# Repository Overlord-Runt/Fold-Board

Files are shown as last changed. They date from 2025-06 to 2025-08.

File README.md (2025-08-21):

# Fold Board
Made By Overlord Runt // Taran The Idiot
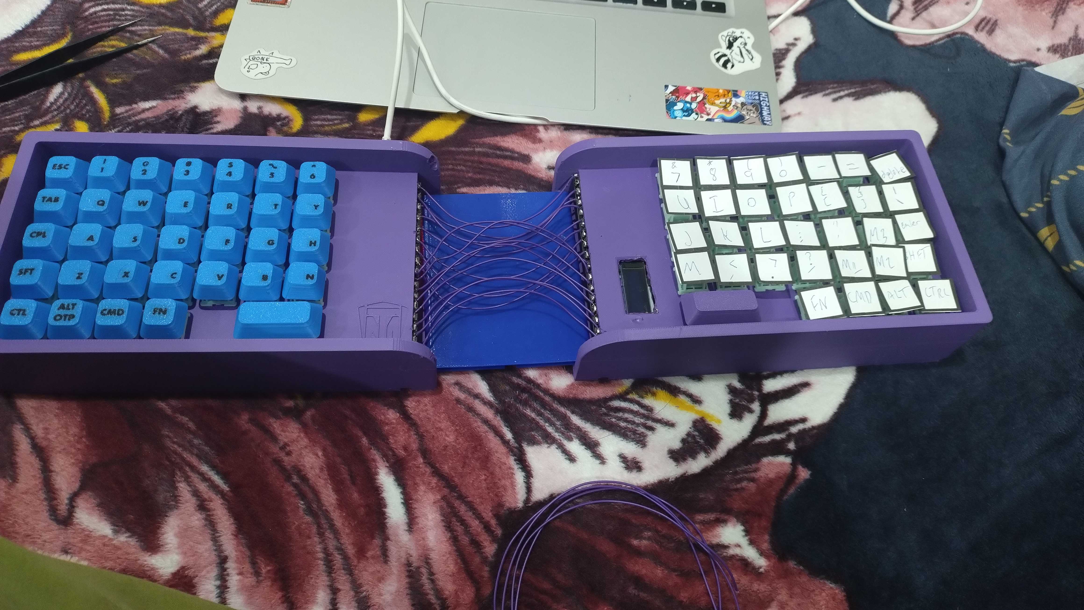
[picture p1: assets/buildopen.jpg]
start


## The Fold Board
Its the second keyboard in my line of Taranium boards. It is a keyboard that folds! It has 66 Keys and an OLED for funny stuff.

If you like this project, please give it a star!

YouTube vid: https://youtube.com/shorts/LQNGhtRMvZQ?si=ZyAIBXtM6X78Itwt

## CAD

Here is a full [CAD Build](https://cad.onshape.com/documents/464e86edd9a4b3695068071c/w/4e80d06eb9a86776c724470c/e/258c53a4e91dc0ec03e526f0) of the keyboard.\
It uses a rubber band to hold the 2 halves together and I am probably gonna have to work on the joint a bit when i get the parts.

The case is 44cm tall when layed flat out which is pretty good for a folding board. I made sure to keep the joint loose but strong enough to stay on so it doesnt wear down as muhttps://youtube.com/shorts/LQNGhtRMvZQ?si=ZyAIBXtM6X78Itwtch and stays nice. I suggest printing it from petg so you can get more slip.

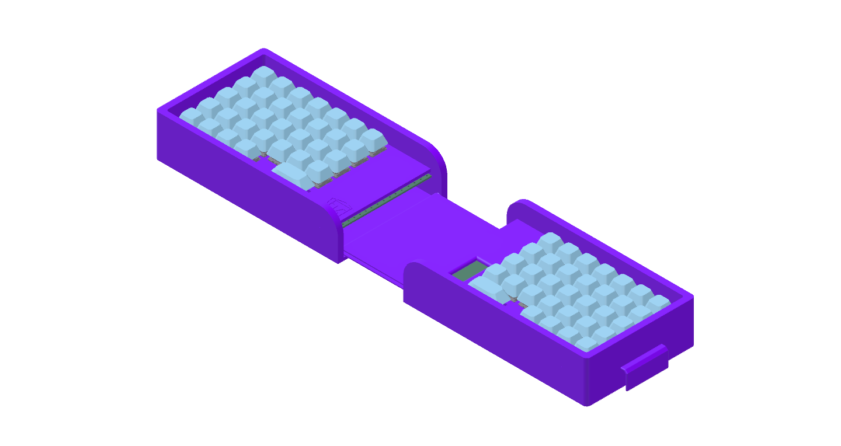
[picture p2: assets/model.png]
mod


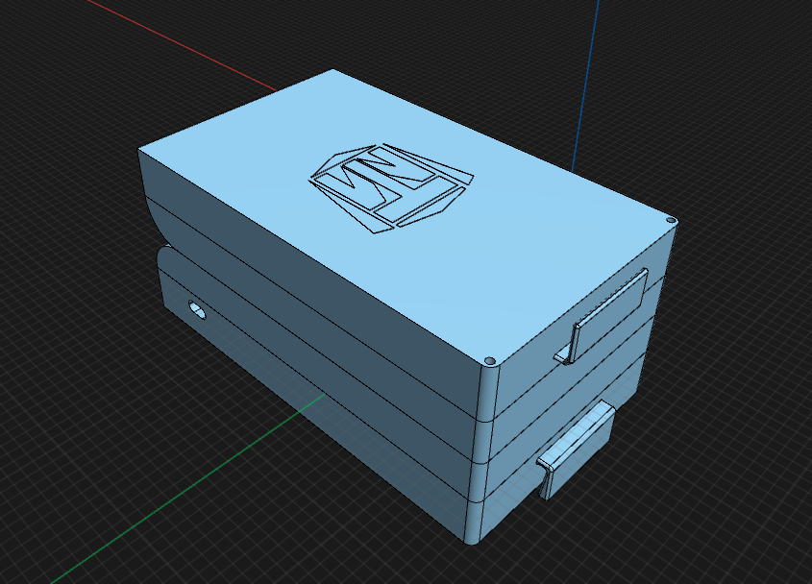
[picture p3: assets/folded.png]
fold


Here are some shots of what it looks like open and folded.

I spent majority of my time here going through different renditions of the bridge and trying different ways to make the fold work while keeping it as a keyboard that it viable to use.

## PCB

The pcb was done pretty quickly and I only did about 1 revision while making it.\
The pcb folder contains the original design files while right and left side have the files with the respective side isolated for fabrication purposes. gerbers can also be found in those folders.

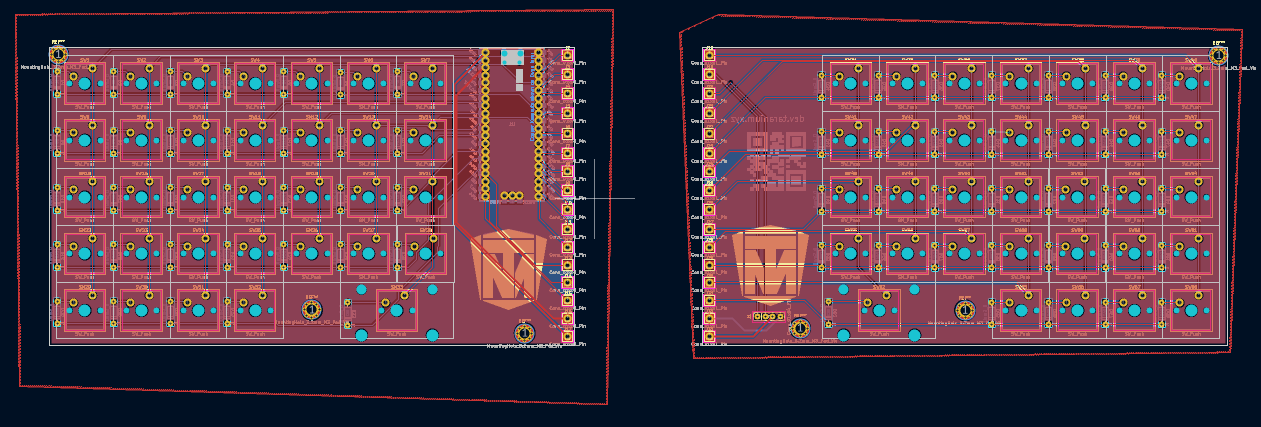
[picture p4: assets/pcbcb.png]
b


I used 16 jumper wires to bridge the connections of one half to the other instead of going for the traditional approach with trrs. I think will add a nice look to it, especially across the bridge.

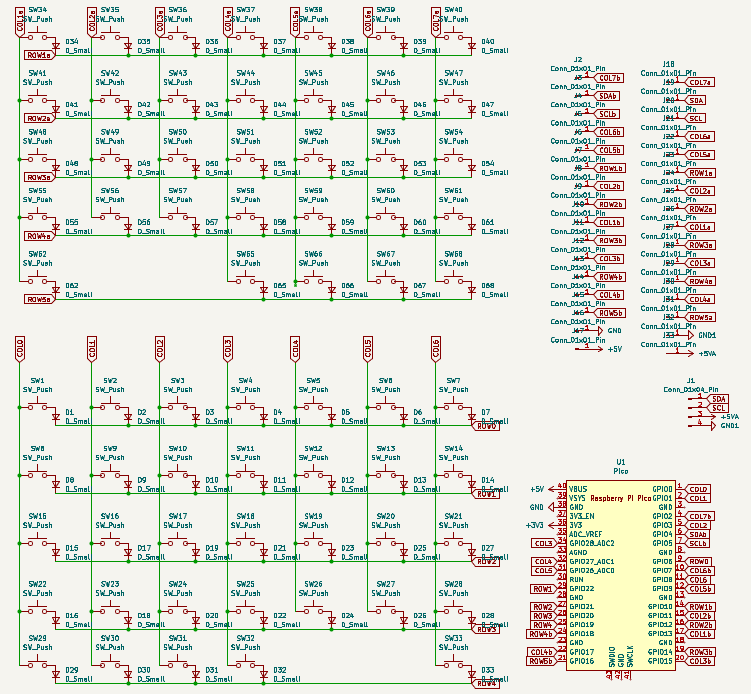
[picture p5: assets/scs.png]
sc


My schematic is pretty normal. Average split board stuff.

## Firmware

This keyboard uses QMK firmware that can be found in the firmware folder. Unfortunately it isnt compiled as my computer is too old to install the QMK command line but I will update it as soon as I can. For now you need to install the command line yourself [here](https://docs.qmk.fm/newbs_getting_started).

This was probably my fastest firmware built ever. Its all thanks to github copilot. It completely gets rid of all the zombie work. I can finally be free. There is no greater blessing to the world.

## BOM
BOM can be found [here](https://github.com/Overlord-Runt/Fold-Board/blob/main/BOM.md) but here is a general list:
- 66 MX Switches
- 66 diodes
- 2 2U stablisers
- 64 1U keycaps
- 2 2U keycaps
- 2 PCBs
- 5 3D printd Case parts
- SSD1306 128x32 OLED
- 16 50mm long wires
- 1 Orpheus Pico(or a normal pico if you dont have one)
- 1 large rubber band
- 8 M3D5L6 Heatsets
- 8 M3 30mm long screws

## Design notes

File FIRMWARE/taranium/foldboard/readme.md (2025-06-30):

# handwired/runtboard

handwired/runtboard

*A short description of the keyboard/project*

* Keyboard Maintainer: [Taran Mittal](https://github.com/Overlord-Runt)
* Hardware Supported: *The PCBs, controllers supported*
* Hardware Availability: *Links to where you can find this hardware*

Make example for this keyboard (after setting up your build environment):

    make handwired/runtboard:default

Flashing example for this keyboard:

    make handwired/runtboard:default:flash

See the [build environment setup](https://docs.qmk.fm/#/getting_started_build_tools) and the [make instructions](https://docs.qmk.fm/#/getting_started_make_guide) for more information. Brand new to QMK? Start with our [Complete Newbs Guide](https://docs.qmk.fm/#/newbs).

## Bootloader

Enter the bootloader in 3 ways:

* **Bootmagic reset**: Hold down the key at (0,0) in the matrix (usually the top left key or Escape) and plug in the keyboard
* **Physical reset button**: Briefly press the button on the back of the PCB - some may have pads you must short instead
* **Keycode in layout**: Press the key mapped to `QK_BOOT` if it is available

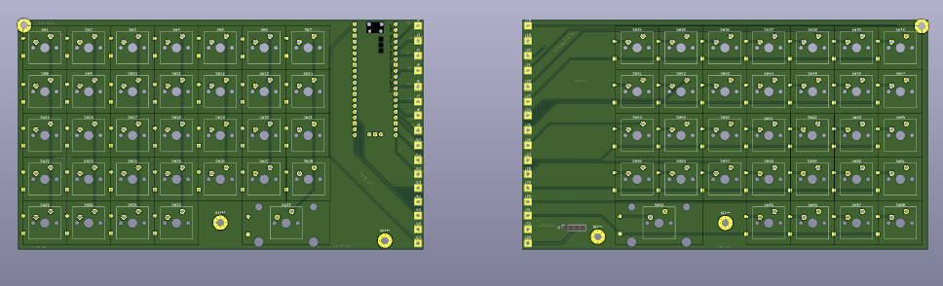
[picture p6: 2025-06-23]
assets/3d.png

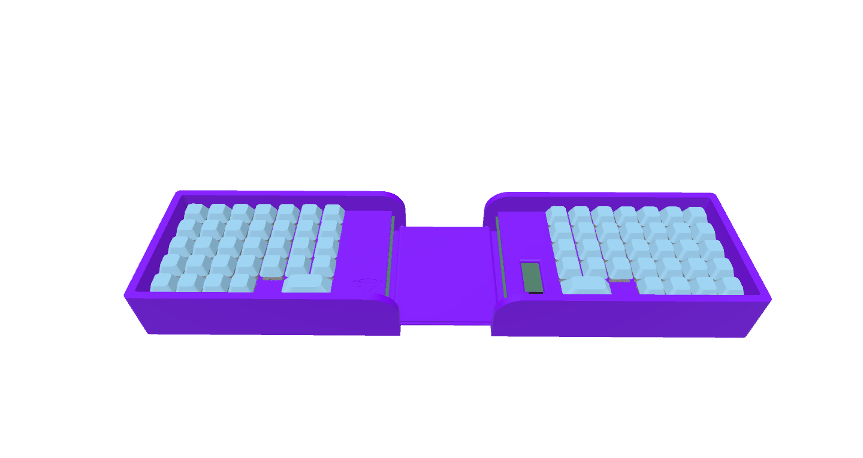
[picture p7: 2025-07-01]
assets/caddy.png

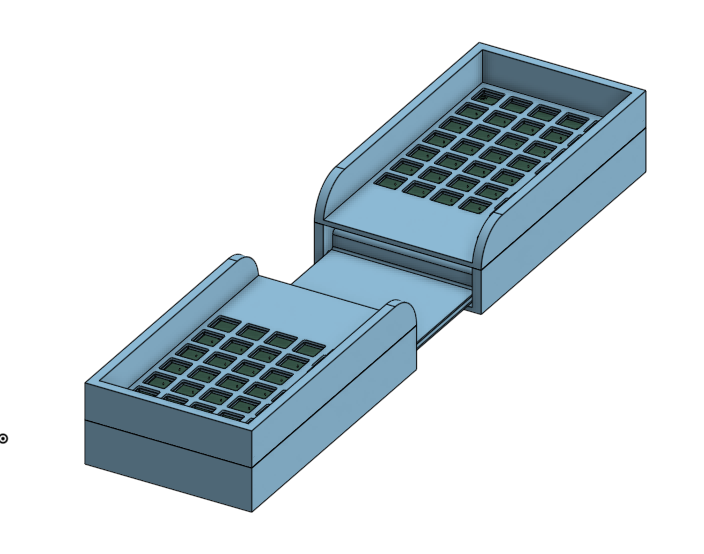
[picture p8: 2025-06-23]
assets/cad2.png

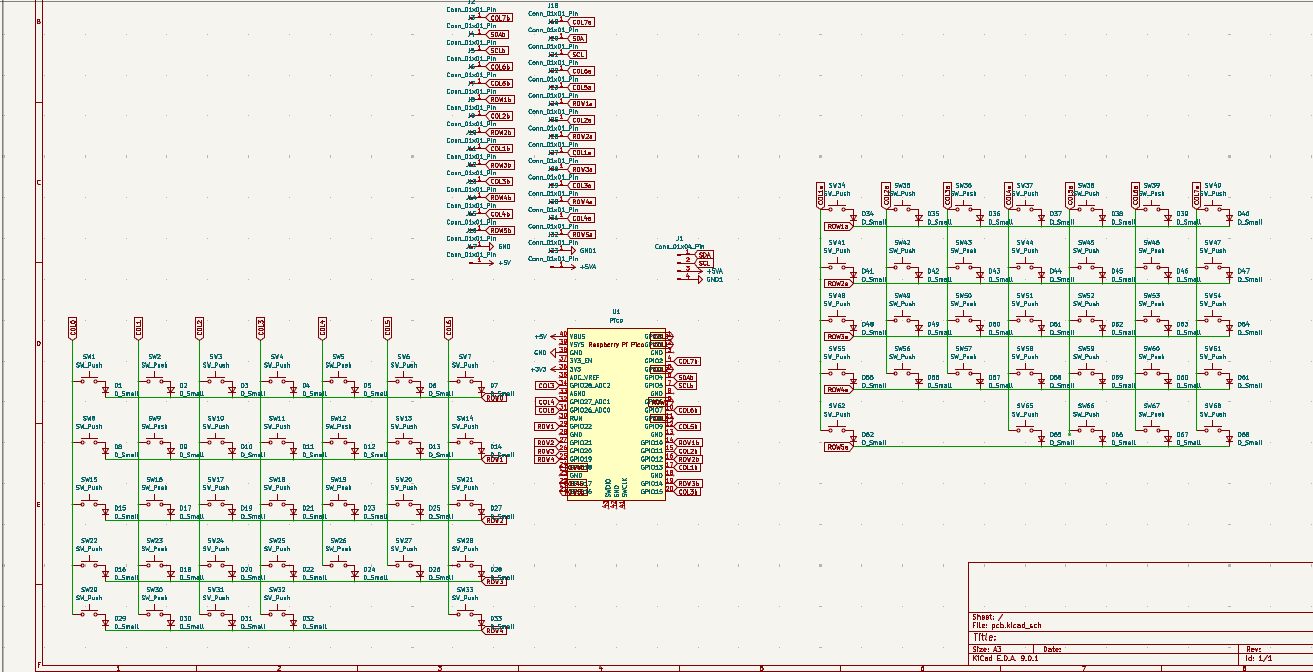
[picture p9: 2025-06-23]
assets/schm.png

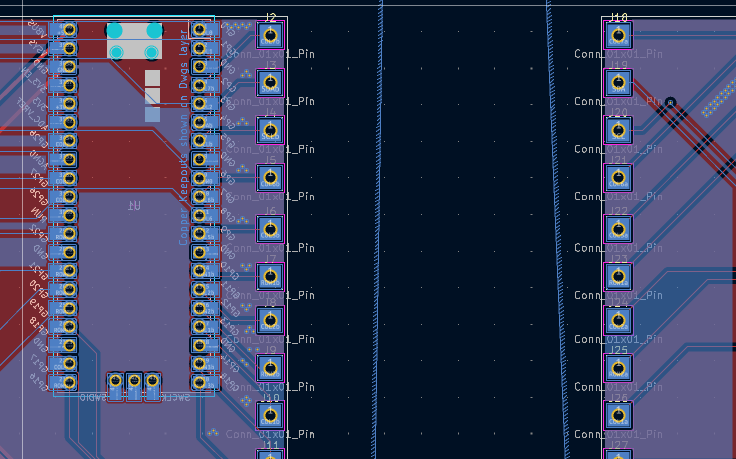
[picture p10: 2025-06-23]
assets/pcb2.png

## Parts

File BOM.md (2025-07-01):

# Bill Of Materials

- 66 MX Switches - $38.47 - [SOURCE](https://www.pccasegear.com/products/67331/akko-botany-switches-45-pack)
- 66 diodes - $1.81 - [SOURCE](https://www.aliexpress.com/item/4000142272546.html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)
- 2 2U stablisers - $4 - [SOURCE](https://www.aliexpress.com/item/1005003263135132.html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)
- 64 1U keycaps - filament costs or keycaps
- 2 2U keycaps - filament or keycaps cost
- 2 PCBs - $33.59 - JLCPCB
- 5 3D printd Case parts - whatever your filament costs
- SSD1306 128x32 OLED - $2.78 - [SOURCE](https://www.aliexpress.com/item/1005008640108394.html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)
- 16 50mm long wires - $1.12 - [SOURCE](https://www.aliexpress.com/item/1005001698211718.html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)
- 1 Orpheus Pico(or a normal pico if you dont have one) - idk but i got it free
- 1 large rubber band - $3.28 - [SOURCE](https://www.aliexpress.com/item/1005007589123213.html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)
- 8 M3D5L6 Heatsets - $2.27 - [SOURCE](https://www.aliexpress.com/item/1005003582355741.html?spm=a2g0o.order_list.order_list_main.29.43e81802OMJWCy)
- 8 M3 30mm long screws - $3.42 - [SOURCE](https://www.aliexpress.com/item/32810852732.html?spm=a2g0o.order_list.order_list_main.53.13191802B8kPkm)

Total Cost(USD): $90.74

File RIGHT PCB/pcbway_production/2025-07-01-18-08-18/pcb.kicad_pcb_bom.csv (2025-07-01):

Designator | Quantity | Value | Footprint | Package | MPN | DNP | Mount_Type | Description | Sim.Device | Sim.Pins
D34, D35, D36, D37, D38, D39, D40, D41, D42, D43, D44, D45, D46, D47, D48, D49, D50, D51, D52, D53, D54, D55, D56, D57, D58, D59, D60, D61, D62, D65, D66, D67, D68 | 33 | D_Small | D_DO-35_SOD27_P7.62mm_Horizontal |  |  |  | tht | Diode, small symbol | D | 1=K 2=A
J1 | 1 | Conn_01x04_Pin | PinSocket_1x04_P2.54mm_Vertical |  |  |  | tht | Generic connector, single row, 01x04, script generated
J18, J19, J20, J21, J22, J23, J24, J25, J26, J27, J28, J29, J30, J31, J32, J33 | 16 | Conn_01x01_Pin | TestPoint_Pad_3.0x3.0mm |  |  |  | tht | Generic connector, single row, 01x01, script generated
SW34, SW35, SW36, SW37, SW38, SW39, SW40, SW41, SW42, SW43, SW44, SW45, SW46, SW47, SW48, SW49, SW50, SW51, SW52, SW53, SW54, SW55, SW56, SW57, SW58, SW59, SW60, SW61, SW65, SW66, SW67, SW68 | 32 | SW_Push | SW_Cherry_MX_1.00u_PCB |  |  |  | tht | Push button switch, generic, two pins
SW62 | 1 | SW_Push | SW_Cherry_MX_2.00u_PCB |  |  |  | tht | Push button switch, generic, two pins

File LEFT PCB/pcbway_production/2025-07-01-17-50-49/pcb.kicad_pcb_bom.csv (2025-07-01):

Designator | Quantity | Value | Footprint | Package | MPN | DNP | Mount_Type | Description | Sim.Device | Sim.Pins
D1, D10, D11, D12, D13, D14, D15, D16, D17, D18, D19, D2, D20, D21, D22, D23, D24, D25, D26, D27, D28, D29, D3, D30, D31, D32, D33, D4, D5, D6, D7, D8, D9 | 33 | D_Small | D_DO-35_SOD27_P7.62mm_Horizontal |  |  |  | tht | Diode, small symbol | D | 1=K 2=A
J10, J11, J12, J13, J14, J15, J16, J17, J2, J3, J4, J5, J6, J7, J8, J9 | 16 | Conn_01x01_Pin | TestPoint_Pad_3.0x3.0mm |  |  |  | tht | Generic connector, single row, 01x01, script generated
SW1, SW10, SW11, SW12, SW13, SW14, SW15, SW16, SW17, SW18, SW19, SW2, SW20, SW21, SW22, SW23, SW24, SW25, SW26, SW27, SW28, SW29, SW3, SW30, SW31, SW32, SW4, SW5, SW6, SW7, SW8, SW9 | 32 | SW_Push | SW_Cherry_MX_1.00u_PCB |  |  |  | tht | Push button switch, generic, two pins
SW33 | 1 | SW_Push | SW_Cherry_MX_2.00u_PCB |  |  |  | tht | Push button switch, generic, two pins
U1 | 1 | Pico | RPi_Pico_SMD_TH |  |  |  | tht

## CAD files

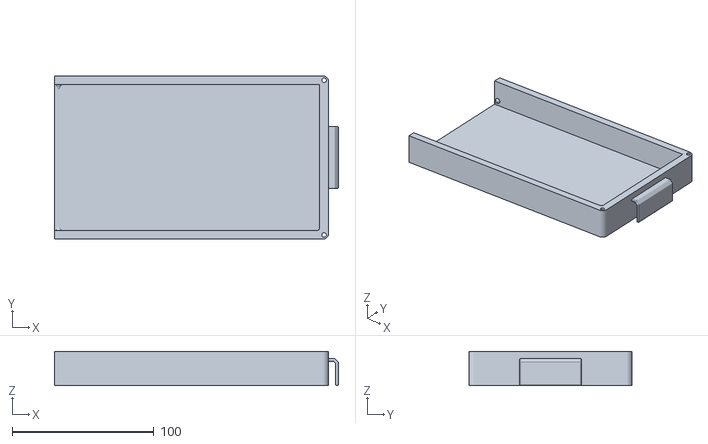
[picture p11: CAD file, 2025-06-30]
PRODUCTION/RIGHT-BOTTOM.stl
200.3 x 115.2 x 24.0

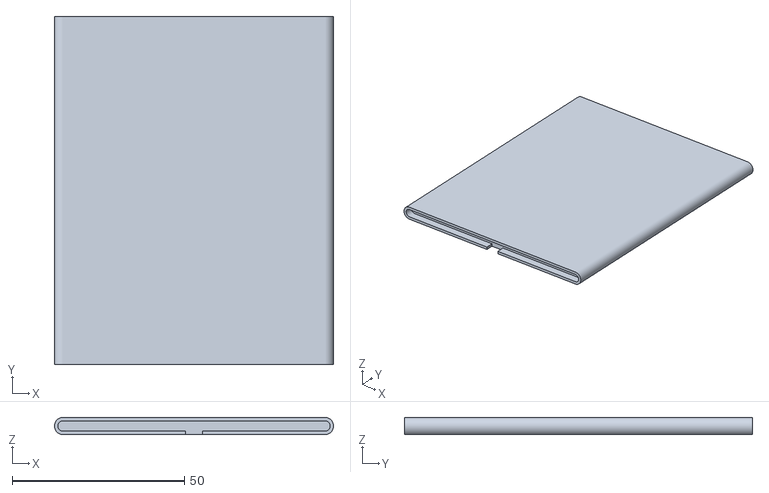
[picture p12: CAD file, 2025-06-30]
PRODUCTION/BRIDGE.stl
81.0 x 101.0 x 5.00

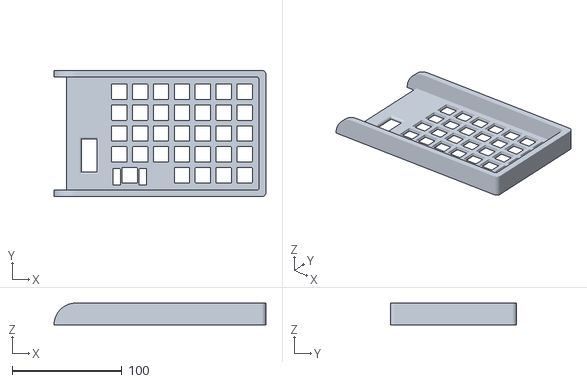
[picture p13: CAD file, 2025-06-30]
PRODUCTION/RIGHT-TOP.stl
193.3 x 115.2 x 20.0

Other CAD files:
PRODUCTION/LEFT-BOTTOM.stl
PRODUCTION/LEFT-TOP.stl

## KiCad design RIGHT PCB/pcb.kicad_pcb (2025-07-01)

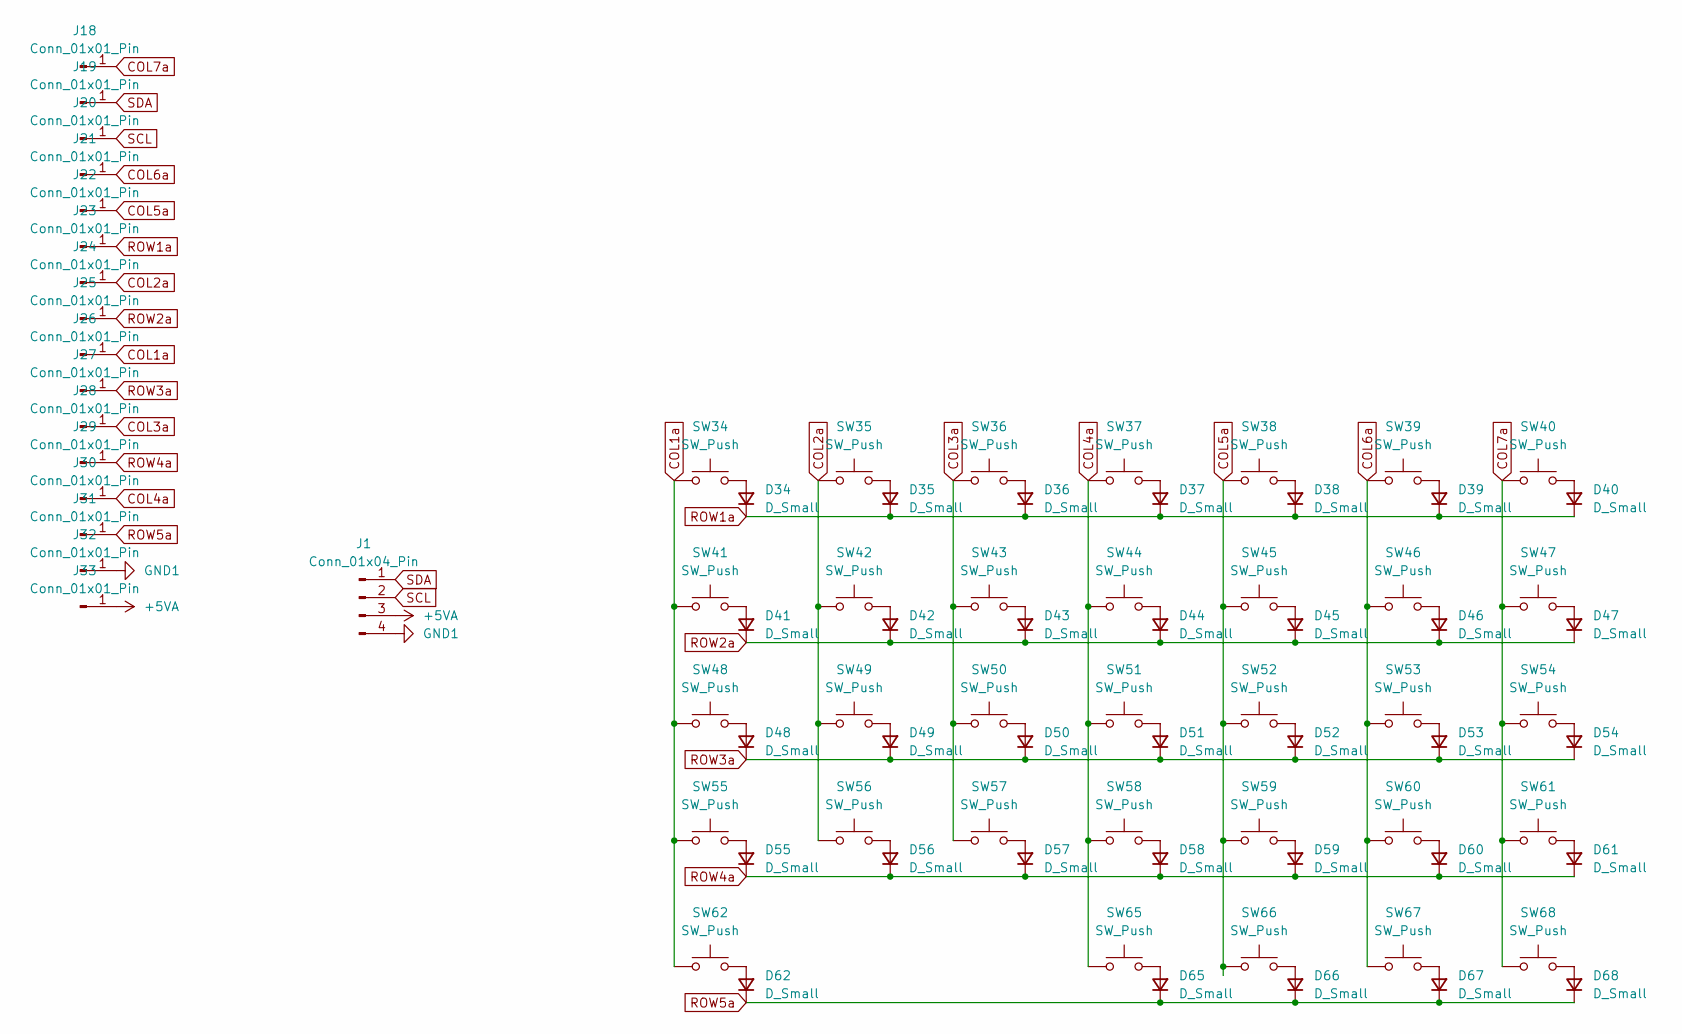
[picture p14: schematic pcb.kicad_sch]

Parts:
D34, D35, D36, D37, D38, D39, D40, D41, D42, D43, D44, D45, D46, D47, D48, D49, D50, D51, D52, D53, D54, D55, D56, D57, D58, D59, D60, D61, D62, D65, D66, D67, D68: D_Small; D_DO-35_SOD27_P7.62mm_Horizontal
J1: Conn_01x04_Pin; PinSocket_1x04_P2.54mm_Vertical
J18, J19, J20, J21, J22, J23, J24, J25, J26, J27, J28, J29, J30, J31, J32, J33: Conn_01x01_Pin; TestPoint_Pad_3.0x3.0mm
SW34, SW35, SW36, SW37, SW38, SW39, SW40, SW41, SW42, SW43, SW44, SW45, SW46, SW47, SW48, SW49, SW50, SW51, SW52, SW53, SW54, SW55, SW56, SW57, SW58, SW59, SW60, SW61, SW65, SW66, SW67, SW68: SW_Push; SW_Cherry_MX_1.00u_PCB
SW62: SW_Push; SW_Cherry_MX_2.00u_PCB

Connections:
+5VA: J1.3, J33.1
COL1a: J26.1, SW34.1, SW41.1, SW48.1, SW55.1, SW62.1
COL2a: J24.1, SW35.1, SW42.1, SW49.1, SW56.1
COL3a: J28.1, SW36.1, SW43.1, SW50.1, SW57.1
COL4a: J30.1, SW37.1, SW44.1, SW51.1, SW58.1, SW65.1
COL5a: J22.1, SW38.1, SW45.1, SW52.1, SW59.1, SW66.1
COL6a: J21.1, SW39.1, SW46.1, SW53.1, SW60.1, SW67.1
COL7a: J18.1, SW40.1, SW47.1, SW54.1, SW61.1, SW68.1
GND1: J1.4, J32.1
unnamed: D34.2 (A), SW34.2
unnamed: D35.2 (A), SW35.2
unnamed: D36.2 (A), SW36.2
unnamed: D37.2 (A), SW37.2
unnamed: D38.2 (A), SW38.2
unnamed: D39.2 (A), SW39.2
unnamed: D40.2 (A), SW40.2
unnamed: D41.2 (A), SW41.2
unnamed: D42.2 (A), SW42.2
unnamed: D43.2 (A), SW43.2
unnamed: D44.2 (A), SW44.2
unnamed: D45.2 (A), SW45.2
unnamed: D46.2 (A), SW46.2
unnamed: D47.2 (A), SW47.2
unnamed: D48.2 (A), SW48.2
unnamed: D49.2 (A), SW49.2
unnamed: D50.2 (A), SW50.2
unnamed: D51.2 (A), SW51.2
unnamed: D52.2 (A), SW52.2
unnamed: D53.2 (A), SW53.2
unnamed: D54.2 (A), SW54.2
unnamed: D55.2 (A), SW55.2
unnamed: D56.2 (A), SW56.2
unnamed: D57.2 (A), SW57.2
unnamed: D58.2 (A), SW58.2
unnamed: D59.2 (A), SW59.2
unnamed: D60.2 (A), SW60.2
unnamed: D61.2 (A), SW61.2
unnamed: D62.2 (A), SW62.2
unnamed: D65.2 (A), SW65.2
unnamed: D66.2 (A), SW66.2
unnamed: D67.2 (A), SW67.2
unnamed: D68.2 (A), SW68.2
ROW1a: D34.1 (K), D35.1 (K), D36.1 (K), D37.1 (K), D38.1 (K), D39.1 (K), D40.1 (K), J23.1
ROW2a: D41.1 (K), D42.1 (K), D43.1 (K), D44.1 (K), D45.1 (K), D46.1 (K), D47.1 (K), J25.1
ROW3a: D48.1 (K), D49.1 (K), D50.1 (K), D51.1 (K), D52.1 (K), D53.1 (K), D54.1 (K), J27.1
ROW4a: D55.1 (K), D56.1 (K), D57.1 (K), D58.1 (K), D59.1 (K), D60.1 (K), D61.1 (K), J29.1
ROW5a: D62.1 (K), D65.1 (K), D66.1 (K), D67.1 (K), D68.1 (K), J31.1
SCL: J1.2, J20.1
SDA: J1.1, J19.1

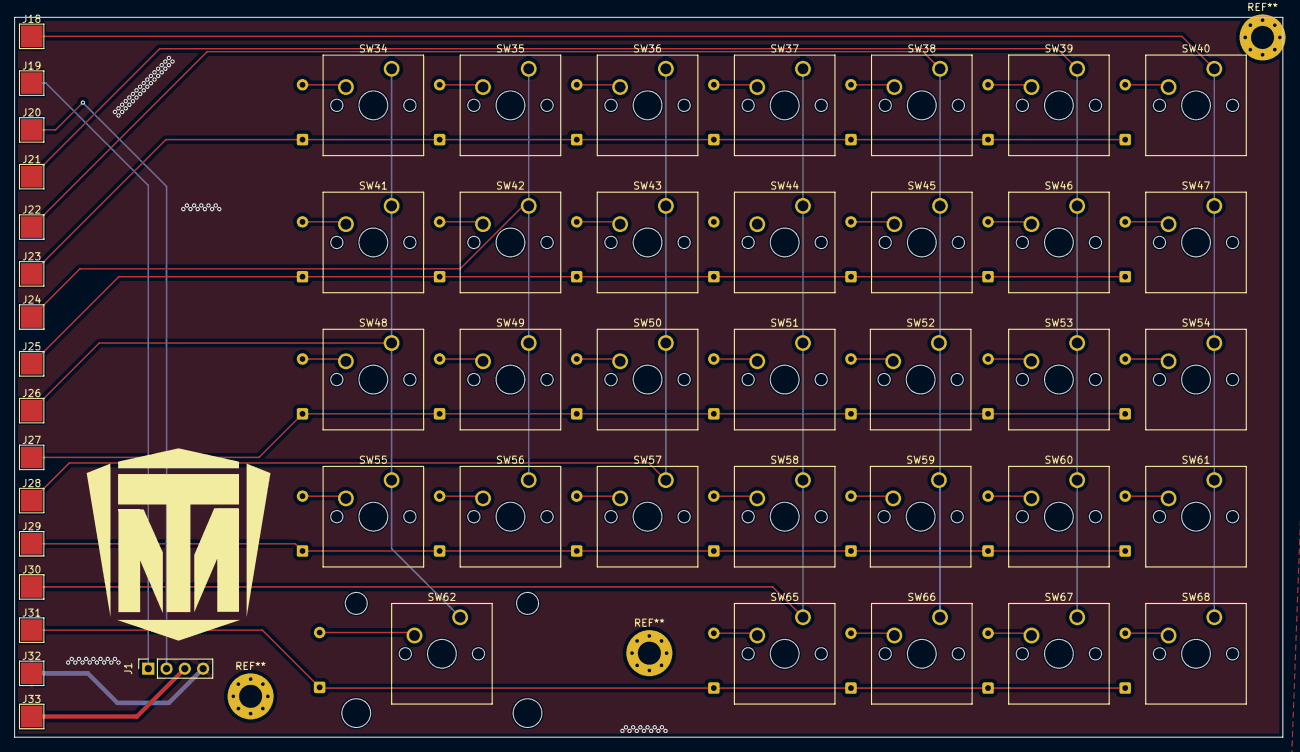
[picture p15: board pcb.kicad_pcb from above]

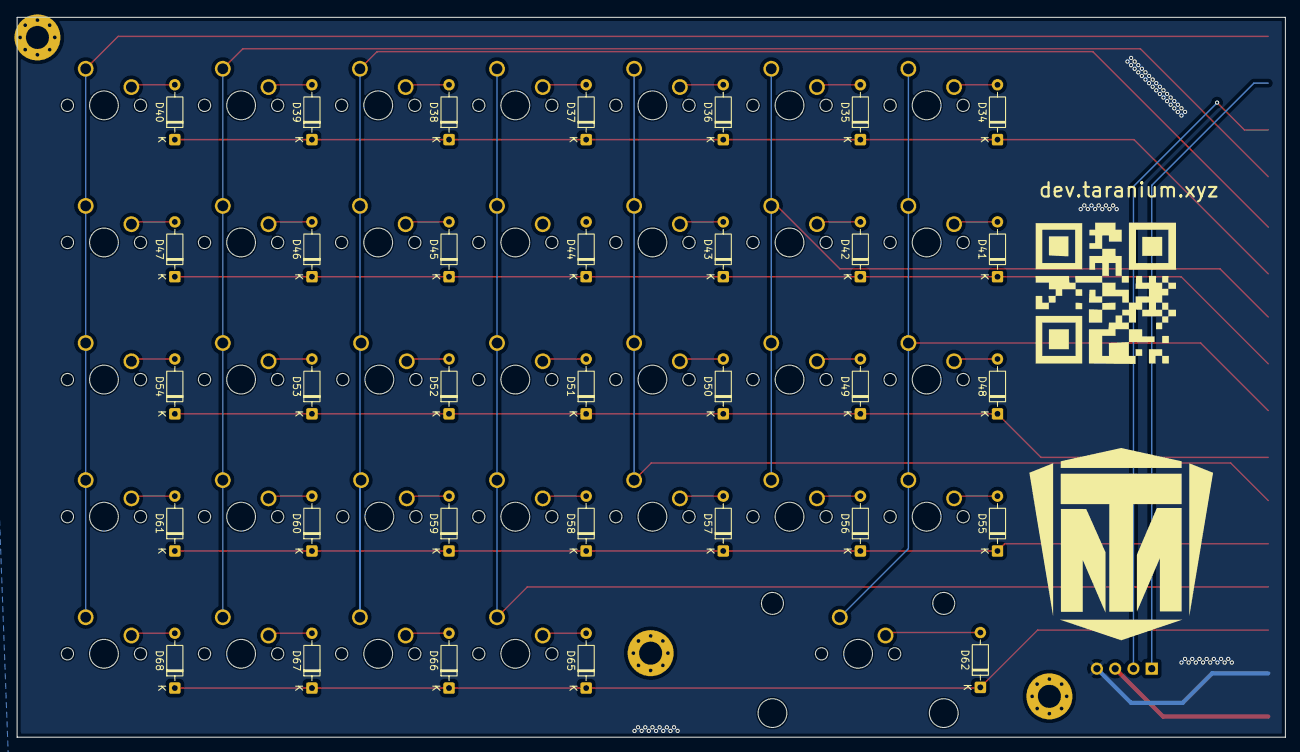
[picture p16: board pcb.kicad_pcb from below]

Board: 2 copper layers, 176.2 x 100.0 mm, 83 parts (33 on the bottom side), 49 nets.

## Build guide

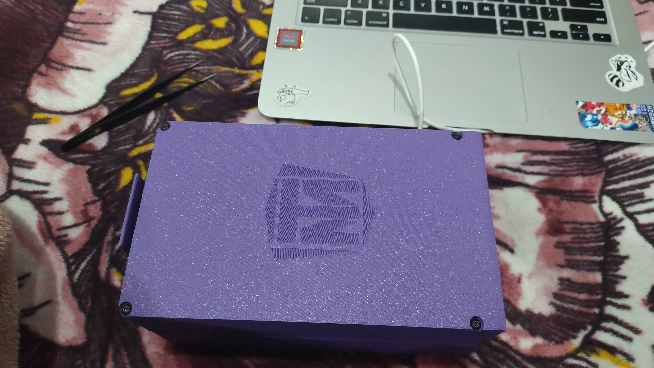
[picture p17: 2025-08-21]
assets/buildclose.jpg

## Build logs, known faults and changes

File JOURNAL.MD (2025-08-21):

---
title: "Fold Board"
author: "Taran The Idiot"
description: "Keyboard That folds"
created_at: "2024-03-20"
---

# The Fold Board!

This is a super cool keyboard that I am making

It folds!

and fits nicely in a bag

Total Time spent: 38

## 13th of June

Did the entire pcb in one day.

Since this is technically a split board, I would normally have needed 2 micro controllers and ttrs. But I aint doing allat.

My design uses one microcontroller and uses 16 wires to connect the 2 halves and bring the right side matrix to the left.

The wires can also function as the way the 2 boards are held together(joke there will be more supports)

I still need to add silkscreen so its not technically done but functionality is done.

Anyways explaining the keyboard.

Its a normal keyboard thats about 75%ish idk it has 84 keys. 

it folds and has 16 wires to connect it together

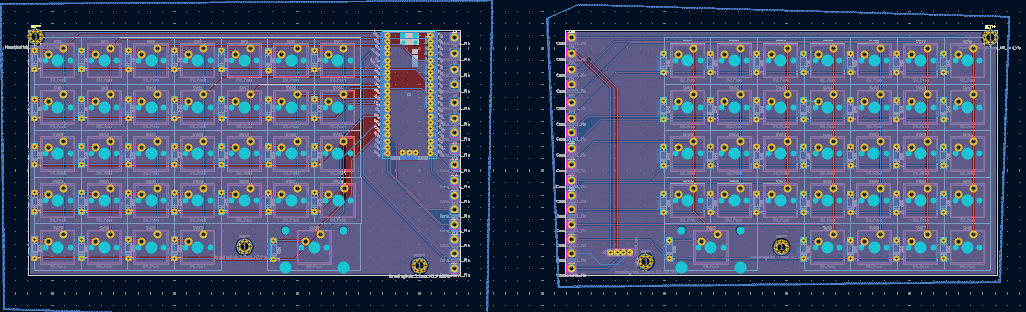
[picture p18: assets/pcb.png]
pcb


Hours spent: 4

## 15th of June

Started work on the case and trying to guage out how I am going to figure out how to have the 2 halves connect and how I want it to look

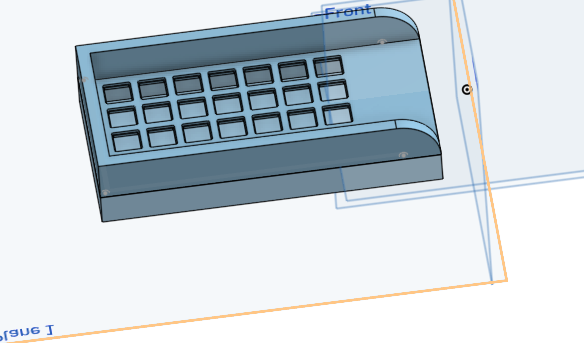
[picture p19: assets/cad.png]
cad


Got this so far, spent a few hours on it and looks kinda nice. might do some more work onto it before moving to the fold

Hours spent: 2

## 17-20th June

Did little bits and bobs of work, not too much but small touches on the pcb, and cad whereever i got time.
total time across these days is like 2 hours max

## 21st of June

I am actually stupid.

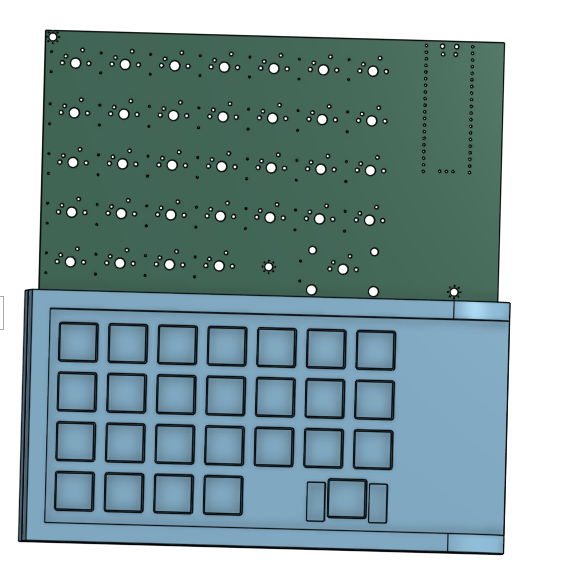
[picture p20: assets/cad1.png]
bah


can you spot the problem here?

thats right

i put 4 rows instead of 5

time to start from scratch again. YAAYAYAYAYA

anyways did lots of work today on my case, went through a few designs, got some of the nitty gritty down, also did a few touches on the pcb but nothing significant.

Time spent: 4 hours

## 23rd of June

Today I went through some designs for the bridge of the 2 halves.

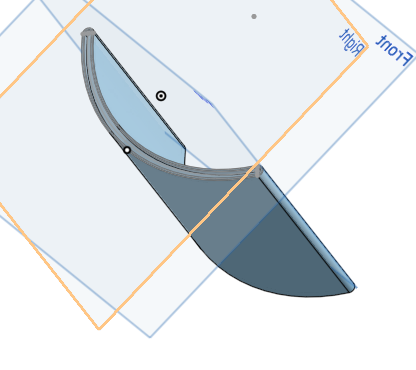
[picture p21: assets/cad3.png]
boo


This is what I was originally going for but that doesn't really fit well with the rest of the model. so then I tried a different one.

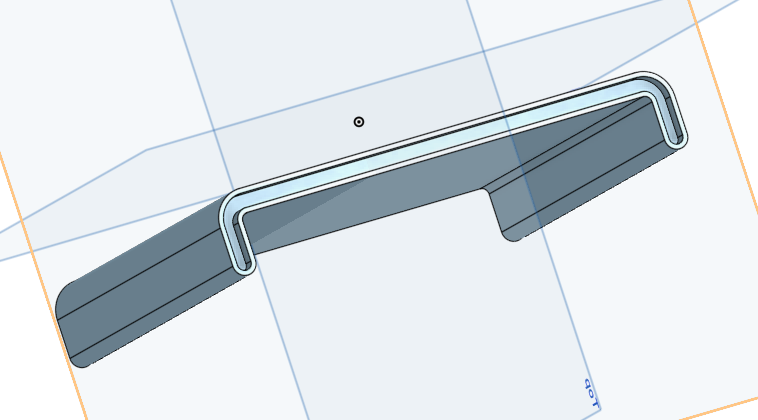
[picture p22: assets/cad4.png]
njfnj


This one is more straightforward and allows me to make it a bit slimmer. idk if i mentioned this before but i want to be able to push these 2 halves together when it lays on a table. to the bridge needs to be able to fit in the case.

In the end I just settled for a completely flat bridge. I had the curve before because it would go around the top plate but now I had shortened the pcb and plate in order to give the bridge room to sit.

Time Spent: 5 hours

## 29th of June

Okay time to start grinding ts.

I polished up on the case and started adding final details with usb port placement and added the proper placements for keycaps and added my logo onto it.

## Time spent: 2 hours

## 30th of June

Firmware time!

I reinstalled mac and turns out my mac is too old to install qmk so I cant compile code and have to copy paste previous firmware folders and then change the pins and keymaps. Also github copilot is soooooooo good. i love it i love it i love it

It saved me soooooo much time with firmware writing.

it does all the zombie work for you

Sure it has a few hiccups but its still amazing

Time spent: 2 hours

## 1st of June 

I just realised that I need to have some sort of thing to hold it together.

So I made a bit that uses a rubber band to hold

djf

Looks like that for now. might change if it doesnt work

Then I made my BOM by scouring for a bit on aliexpress but most of the stuff was easy to find since i have made a board before and I just used the same places.

Then the readme. That was nice. I think it looks nice, better than my last one at least

Time spent 4 hours

## 2nd of June

Submitted :D

## 17th of July

Came back from underity and am pooped. the parts arrived a bit back just after I left. anyways i will update

## 18th of July
Soldered the pcb and printed the case.
Kinda messed up the screw holes so need to fix that

hours spent: 5

## 20th of July

Finished the base and now I need to make Keycaps. but will put it off a bit to finish my other project

hours spent: 2

## 2nd Of August

Made half the keycaps and it took me so long to line everything up :sob:

But they didnt even fit :(
 It fits enough to stay on but not enough to go all the way down on the stem. going to have to add more tolerance to it.

anyways that sucks but meh. imma take a break for a bit cuz im not bothered rn

Time spent: 2 hours

## 13th of August

My printer had a poop of death :sob:

Im cooked

# 21st of august

Replaced the centre wires with longer ones because they kept snapping. also made paper keycaps because I cant do printed ones. I just stuck them on with blu tack.

Anyways done :)

aasd

Time Spent: 4 hours
